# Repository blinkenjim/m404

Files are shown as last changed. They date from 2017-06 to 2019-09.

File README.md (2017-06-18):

M404 Monitor
------------

The M404 monitor is a device to display status for a headless
Raspberry Pi (or any other computer with a USB port).

For more information see doc/design-notes.md.

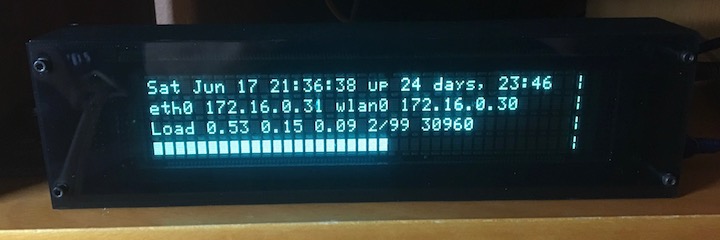
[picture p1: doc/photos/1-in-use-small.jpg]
M404 Monitor in use


The monitor is built around a Futaba M404SD01 Vacuum Fluorescent
Display (VFD) module. This module has a display of 40 characters by 4
lines. In addition to the VFD module, the monitor consists of:

1. A 3D printed case.

2. Laser-cut acrylic front and back covers.

2. An Arduino Nano that drives the VFD module.

3. A Python script that runs on the Raspberry Pi to gather data for
   display.

This project includes all the code, schematics, 3D models, and assembly 
information necessary to build and use an M404 monitor.

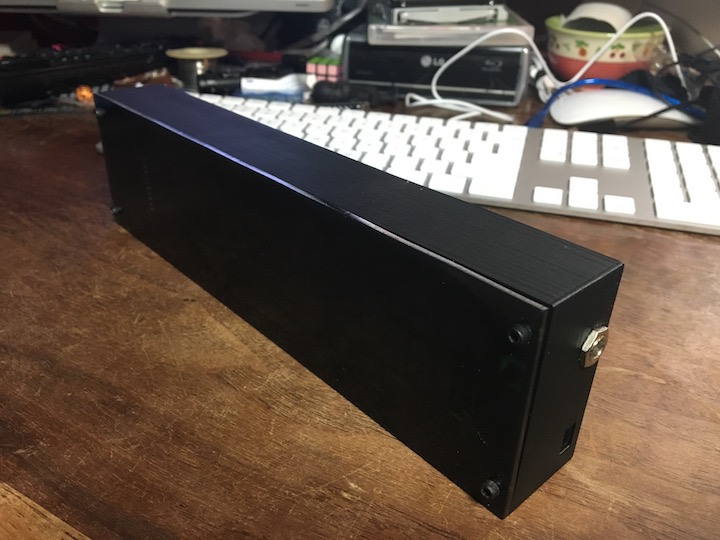
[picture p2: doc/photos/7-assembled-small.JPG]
M404 Monitor Fully Assembled


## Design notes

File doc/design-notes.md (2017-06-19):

M404 Monitor
============

Introduction
------------

The M404 Monitor is a device to display status for a headless
Raspberry Pi (or any other computer with a USB port).

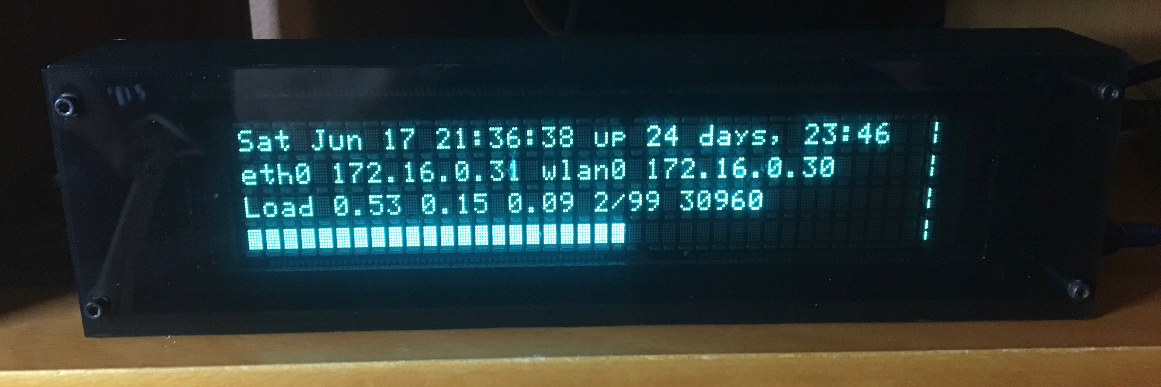
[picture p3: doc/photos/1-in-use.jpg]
M404 Monitor in use


The monitor is built around a Futaba M404SD01 Vacuum Fluorescent
Display (VFD) module. This module has a display of 40 characters by 4
lines. In addition to the VFD module, the monitor consists of:

1. A 3D printed case.

2. Laser-cut acrylic front and back covers.

2. An Arduino Nano that drives the VFD module.

3. A Python script that runs on the Raspberry Pi to gather data for
   display.

3D Printed Case
---------------

The case was designed in Autodesk Fusion. The case is almost 10 inches
long and requires a printer with a fairly large print bed. I printed
mine on a re:3d Gigabot at the Jocelyn H Lee Innovation Lab at the
Freeman branch of the Harris County Public Library in Houston.

I have included an export of the Fusion project files, but should note
that I have never tried to work from an export (Fusion stores its
designs in the cloud, and I always work from these copies).

Also included is an STL model exported from Fusion. **IMPORTANT NOTE**:
when slicing the model for printing, it *MUST* be mirrored along the Y
axis (long axis) or the print will be unusable.

The 3D model files are in the 3d directory.

Laser-Cut Covers
----------------

Included is an SVG file that can be fed to a laser cutter to cut
covers for the case. The SVG file can be used for both the front and
back covers. I use 1/8" translucent grey acrylic for the front cover
and 1/8" opaque black acrylic for the back cover.

The SVG file is in the 3d directory with the STL file.

Arduino Nano
------------

The Nano was chosen for its small size and USB port. The Nano must be
attached to the case with small screws. Most nanos have header pins
soldered to them; these pins make the nano too large to fit in the
case. A nano *without* header pins must be used; these can be found on
Ebay. Wires for power (2) and connection to the VFD module (5) must be
soldered directly to the nano.

The case includes a small port to allow a mini-USB cable to be
attached. Display information is transmitted from the Raspberry Pi
over USB to the nano.

Two Aurdino programs are included:

In arduino/m404-demo is a demo program that displays Lewis Carroll's
poem Jabberwocky on the VFD module. This program can be used to test
the M404 monitor without requiring an external computer to transmit
information over the USB cable.

In arduino/m404-disp is the program that receives information over the
USB connection and drives it to the VFD module.

The reason for using an Arduino as an intermediary to drive the VFD
module, rather than connecting the Raspberry Pi directly to the VFD
module is twofold:

1. The VFD module uses an unusual baud rate and requires monitoring of
   its BUSY signal to keep from losing data.

2. The Arduino program uses a timeout to determine whether the
   Raspberry Pi or its script have stopped running. If a 10-second
   interval passes without any communication from the Raspberry Pi,
   the program will display a message reading "HOST NOT
   RESPONDING". This would not be possible if the Raspberry Pi were
   communicating directly to the VFD module.

The Aurdion uses two serial ports: the built-in serial port on pins 0
and 1 is used to receive information from the Raspberry Pi. A soft
serial port on pins 9 and 10 is used to transmit information to the
VFD module (only the transmit pin, 10, is used and pin 9 is left
unconnected).

Python
------

In the python directory are a pair of scripts that run on the
Raspberry Pi:

1. m404.py is a python script that gathers basic information from the
   Raspberry Pi: date/time, uptime, IP addresses for eth0 and wlan0,
   system load. This information is sent to the nano for display on
   the VFD module. System load is displayed both as text and load
   graph.

2. m404 is a shell script that can be installed in /etc/init.d; this
   allows the python script to be treated as a system service. As a
   system service, linux will automatically start the python script at
   boot, and it can be controlled with the 'service' command:
   e.g. `service m404 start`, `service m404 status`, etc.

Power
-----

A 1/4" hole must be drilled in the case to accept a 2.1mm barrel jack
for power. The hole is not included in the 3D model to allow some
end-user choice of exactly where to locate the jack. I put mine on the
same end of the case as the USB port.

Fasteners
---------

As mentioned above, four tiny screws are required to attach the
Arduino nano to the case. I didn't purchase these screws, but found
four in my small fastener collection (mostly these come from old
devices I've disassembled.

12 larger screws are required: four to attach the VFD module to the
case, and four each to attach the front and backcovers. #4-40 screws
in 1/4" or 3/8" length will work nicely. I prefer [socket cap, alloy
steel black oxide finish] [1] bolts from Bolt Depot.

Assembly Notes
--------------

The CN1 connector on the VFD module is a 2x13 pin IDC header. The
simplest way to connect is to use a matching crimp-on plug with a
26-pin ribbon cable. Only a few of the wires are required, and the
others can be cut short - but leave an inch or two of the full ribbon
cable to give yourself something to grasp when disconnecting the
plug.

When I assemble my M404 monitor, I only had a 2x10 pin plug handy, so
I used that instead. It required that I clip pins 21 and 22 off the
IDC header, otherwise they interfere with the IDC plug. To connect to
Vcc (pins 23 and 24) and GND (pins 25 and 26), I soldered wires
directly to the pins in the header.

It would also be possible to forego the IDC plug entirely, and just
solder directly to the pins in the header.

Reference Information
---------------------

A copy of the documentation for the Futaba M404SD01 Vacuum Fluorescent
Display module is in the ref directory.

Schematic
---------

An Eagle project and schematic are included in the eagle directory
showing the connections required between the Arduino nano, VFD module,
and power jack.

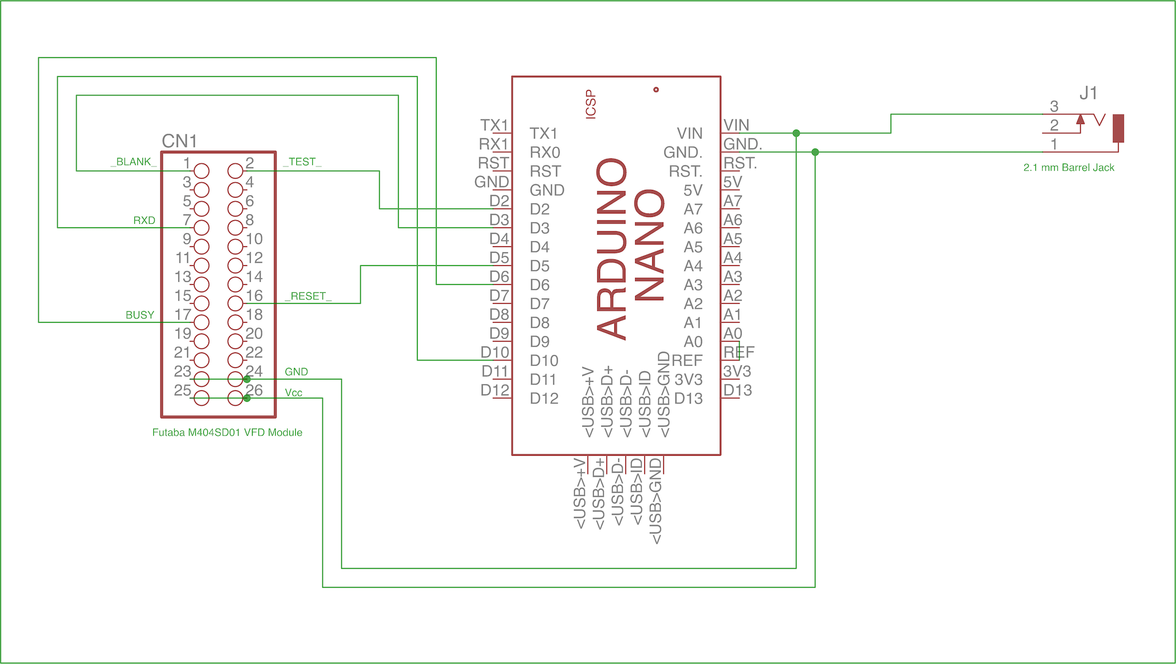
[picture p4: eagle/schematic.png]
Schematic


Photos
------

The M404 monitor with the front cover removed:

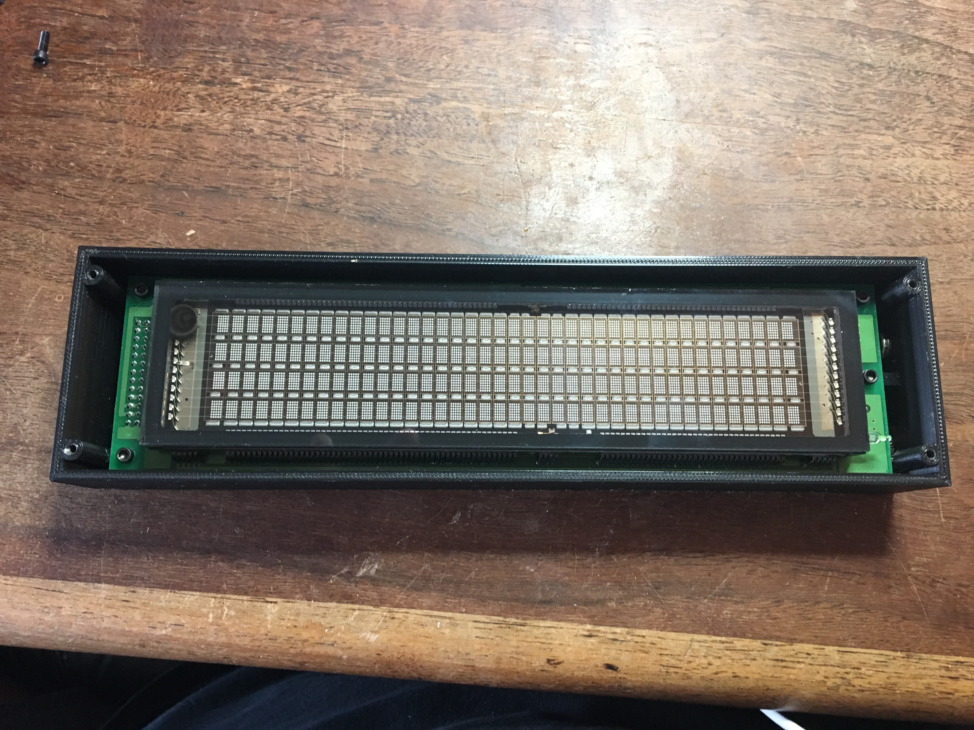
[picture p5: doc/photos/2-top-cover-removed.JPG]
Front View


The M404 monitor with the back cover removed:

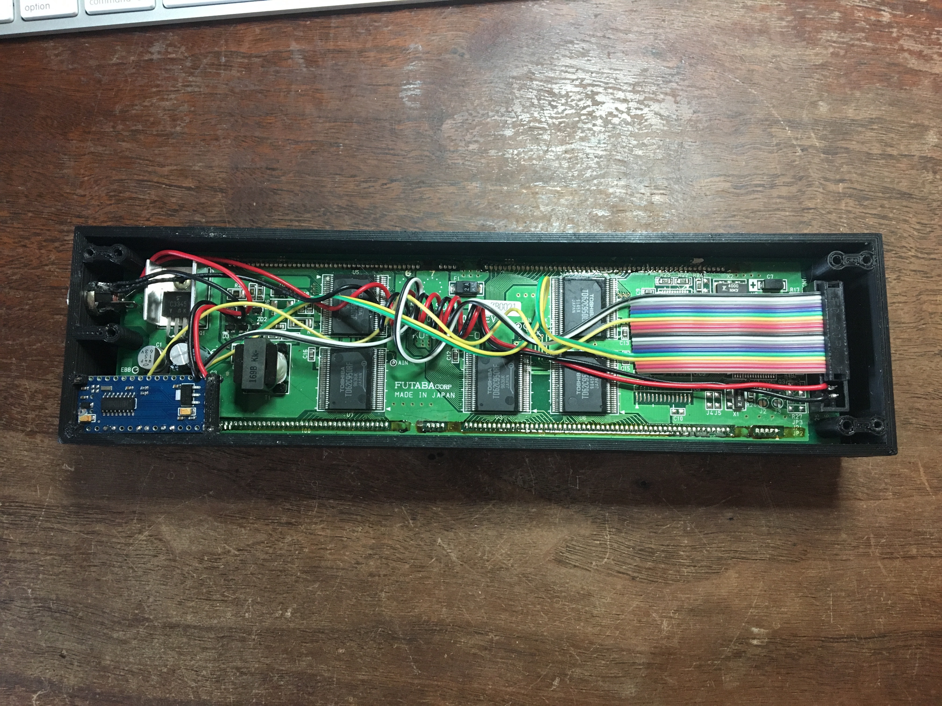
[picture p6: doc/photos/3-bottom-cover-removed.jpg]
Back view


Detail view of the Arduino nano from the bottom:

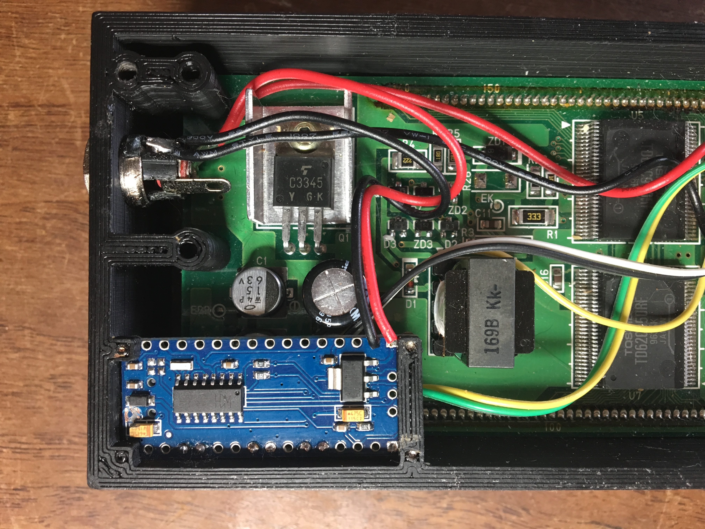
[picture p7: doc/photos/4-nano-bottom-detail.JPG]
Nano detail view back


Detail view of the Arduino nano from the front (with the VFD module removed):

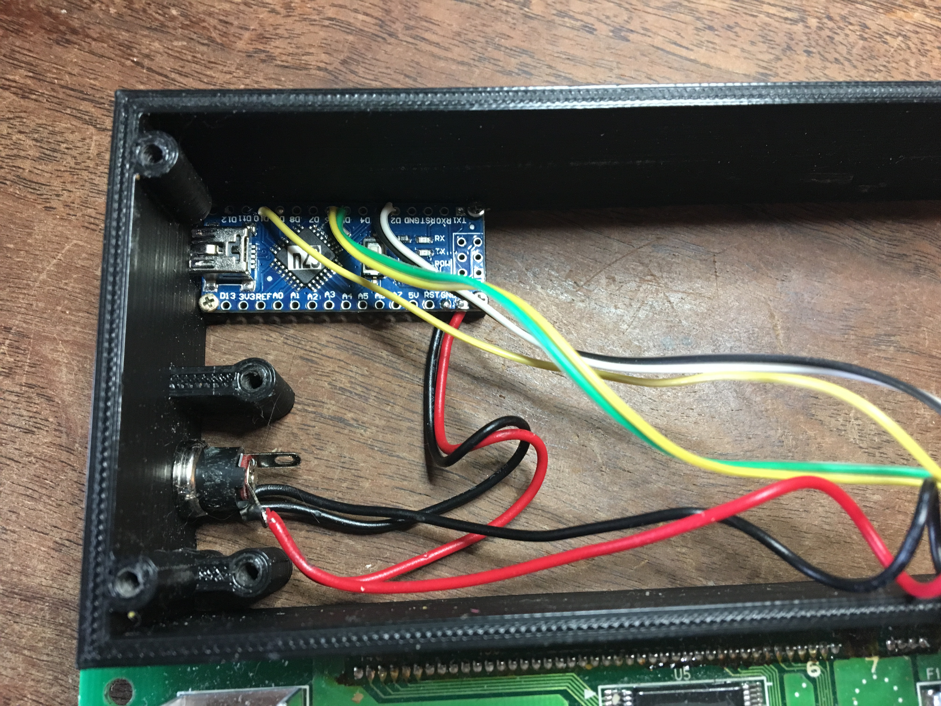
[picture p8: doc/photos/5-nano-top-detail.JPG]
Nano detail view front


Detail view of the interface connector on the VFD module:

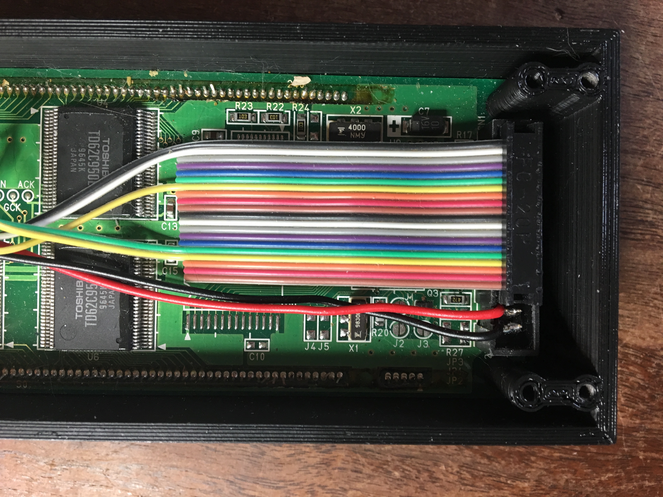
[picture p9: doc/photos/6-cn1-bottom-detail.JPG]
CN1 detail view front


The M404 Monitor fully assembled:

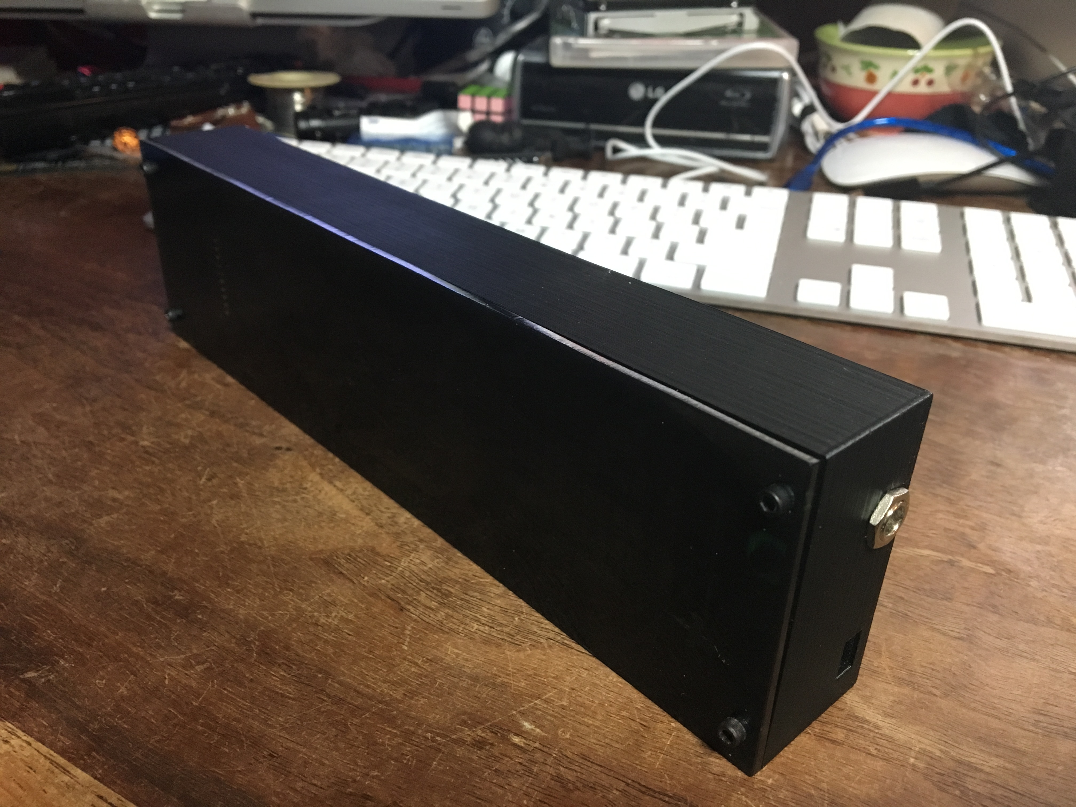
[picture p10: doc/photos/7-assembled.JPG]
Fully assembled


[1]: https://www.boltdepot.com/Socket_cap_Alloy_steel_black_oxide_finish_4-40.aspx?Selected=7872

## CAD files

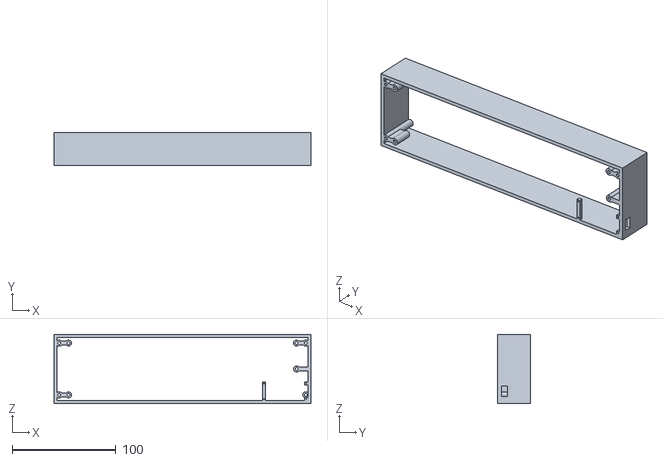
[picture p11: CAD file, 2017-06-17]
3d/Project M404 v11.stl
248.0 x 32.0 x 67.0

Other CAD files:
3d/fusion/Project M404 v11.f3d

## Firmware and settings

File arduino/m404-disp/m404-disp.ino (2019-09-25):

// M404 - A vacuum fluorescent display monitor for Raspberry Pi.
//
// Copyright (c) 2017 James Thompson
//
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
#include <SoftwareSerial.h>

const unsigned int pin_blank_ = 3;
const unsigned int pin_test_ = 2;
const unsigned int pin_reset_ = 5;
const unsigned int pin_busy = 6;

const unsigned int pin_nc = 9;
const unsigned int pin_rxd = 10;

SoftwareSerial mySerial(pin_nc, pin_rxd);

// We must delay a short time after writing each character, or else
// or the module receives garbled text. 440 microseconds seems to be
// the minimum amount we can delay. Also, we must check the busy
// pin before writing the next character. This prevents garbling when
// the text wraps from the end of the display to the beginning.

#define INTERCHAR_DELAY_ONLY 0

// Define the baud and delay values. (Yes, this is a fairly weird
// rate, but it is what the VFD module seems to like.)

#define BAUD 62500
#define DELAY 440

#if defined(INTERCHAR_DELAY_ONLY) && (INTERCHAR_DELAY_ONLY > 0)
#define INTERCHAR_DELAY delayMicroseconds(DELAY)
#else
#define WAIT for (int busy = HIGH; busy == HIGH; busy = digitalRead(pin_busy)) {} 
#define INTERCHAR_DELAY { WAIT; delayMicroseconds(DELAY); WAIT; }
#endif

// Function to print a string to the VFD module with intercharacter delay.

void metered_print(const char *s)
{
    while (*s)
    {
	mySerial.write(*s++);
	INTERCHAR_DELAY;
    }
}

// Function to print a string of specific length to the VFD module
// with intercharacter delay.

void metered_write(const unsigned char *s, unsigned int len)
{
    for(int i = 0; i < len; i++)
    {
	mySerial.write(*s++);
	INTERCHAR_DELAY;
    }
}

// Function to write a single character to the VFD module with
// postcharacter delay.

void metered_write(const unsigned char c)
{
    mySerial.write(c);
    INTERCHAR_DELAY;
}

// The main Arduino setup routine

void setup()
{
    // Set the appropriate modes for the various I/O pins.
    pinMode(pin_busy, INPUT);
    pinMode(pin_blank_, OUTPUT);
    pinMode(pin_test_, OUTPUT);  
    pinMode(pin_reset_, OUTPUT);

    // Reset the VFD module.
    digitalWrite(pin_blank_, HIGH);
    digitalWrite(pin_test_, HIGH);
    digitalWrite(pin_reset_, HIGH);

    // Pause for effect.
    delay(1);

    // Setup the serial port for writing to the VFD.
    mySerial.begin(BAUD);

    // Setup the serial port for writing to the Arduino IDE monitor.
    Serial.begin(115200, SERIAL_8N1);

    // Pause for effect.
    delay(1000);

    // Set the display brightness.
    unsigned char dim_cmd[] = { 0x04, 0xff };
    metered_write(dim_cmd, 2);
}

// The main Arduino event loop

void loop()
{
    metered_print("M404 monitor starting...\n\n");

    // Variables for determining whether we've had a timeout.
    unsigned long last_millis = millis();
    unsigned long now_millis = last_millis;

    // We loop forever, reading characters from the host, and writing
    // those characters to the VFD module.
    while(true)
    {
	// While characters are coming in...
	while (Serial.available() > 0)
	{
	    // Read the character from the host.
	    unsigned char c = Serial.read();

	    // Write the character to the VFD.
	    metered_write(c);
	    last_millis = millis();
	}
    
	now_millis = millis();
    
	if (now_millis < last_millis)
	{
	    // Handle wraparound
	    last_millis = now_millis;
	}
    
	if ((now_millis - last_millis) > 10000) // More than ten seconds since we heard from host?
	{
	    metered_write(0x0b);
	    metered_write(0x13);
	    metered_print("\r\r      *** HOST NOT RESPONDING ***");

	    // Wait for some serial data to appear.
	    while (Serial.available() == 0)
	    {
	    }
	}
    }
}

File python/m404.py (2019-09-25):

#!/usr/bin/python

# M404 - A vacuum fluorescent display monitor for Raspberry Pi.
#
# Copyright (c) 2017 James Thompson
#
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
# Import the various python packages we need.

import socket
import time
import subprocess
from netifaces import interfaces, ifaddresses, AF_INET
import serial
import re
import math

from datetime import timedelta
import signal, os

# Define a signal handler.

def handler(signum, frame):
    ser404.write("\x0b")
    ser404.write("Stopping on signal " + str(signum))
    os.abort()

looptime = 60
ips=''

ser404 = serial.Serial('/dev/ttyUSB0', 115200)

# Catch any of the signals that might cause the process to exit. Note
# that by catching exceptions (later on) seems to cause these signlas
# to get caught as exceptions, so the signal handler does not actually
# run.
#signal.signal(signal.SIGABRT, handler)
signal.signal(signal.SIGALRM, handler)
signal.signal(signal.SIGBUS, handler)
signal.signal(signal.SIGFPE, handler)
signal.signal(signal.SIGHUP, handler)
signal.signal(signal.SIGILL, handler)
signal.signal(signal.SIGINT, handler)
signal.signal(signal.SIGPIPE, handler)
signal.signal(signal.SIGPOLL, handler)
signal.signal(signal.SIGQUIT, handler)
signal.signal(signal.SIGSEGV, handler)
#signal.signal(signal.SIGSTOP, handler) # Can't catch?
signal.signal(signal.SIGSYS, handler)
signal.signal(signal.SIGTERM, handler)
#signal.signal(signal.SIGTSTP, handler) # Don't want to catch
#signal.signal(signal.SIGTTIN, handler) # Don't want to catch
#signal.signal(signal.SIGTTOU, handler) # Don't want to catch
signal.signal(signal.SIGTRAP, handler)
signal.signal(signal.SIGURG, handler)
signal.signal(signal.SIGUSR1, handler)
signal.signal(signal.SIGUSR2, handler)

ser404.write("\x0b")                    # Clear the display
ser404.write("\x13")                    # Set overwrite mode
ser404.write("\x04\xFF")                # Set brightness to max

ser404.write("\x03\xfc\xfc\x63\x18\xc7\xe0")
ser404.write("\x03\xfd\xaa\xaa\xaa\xaa\xaa")

def padout(s):
    s = s + '                                        ' #
    s = s[0:39]
    s += '|'
    return s

#try:
if True:
    while 1:
        allifaces = []
        for ifaceName in interfaces():
            if ifaceName[0:2] != "lo":
                addresses = [i['addr'] for i in ifaddresses(ifaceName).setdefault(AF_INET, [{'addr':'-'}] )]
                name = ifaceName + ' ' + ', '.join(addresses)
                allifaces.append(name)

        ips = ' '.join(allifaces)

        rawup = "0 0"
        with open('/proc/uptime', 'r') as f:
            rawup = f.readline()
            f.close()

        rawsplit = rawup.split()[0]
        uptime_seconds = float(rawsplit)
        # uptime_seconds += 99 * (24 * 60 * 60)
        # uptime_seconds += 23 * 60 * 60

        with open('/proc/loadavg', 'r') as f:
            rawload = f.readline()
            f.close

        load1m = rawload.split()[0]
        load1m = 0.0 + float(load1m)

        (fload, iload) = math.modf(load1m)

        loadbricks = 40 * fload
        ceilbricks = int(math.ceil(loadbricks))

        if ceilbricks > 40:
            ceilbricks = 40

        if ceilbricks == 0:
            g_msg = padout("\xfd")
        else:
            g_msg = padout(ceilbricks * "\x7f")

        cpucount = iload
        cpucounti = int(cpucount)
        
        if cpucounti > 40:
            cpucounti = 40

        for i in range(cpucounti):
            g_msg = g_msg[:i] + '\xfc' + g_msg[i:]
            
        tdelt = timedelta(seconds = uptime_seconds)

        if (uptime_seconds > (10 * 24 * 60 * 60)):
            us = str(tdelt).split(':', 2)
            uptime_string = 'up ' + us[0] + ':' + us[1]
        else:
            uptime_string = 'up ' + str(tdelt).split('.', 2)[0]
            
        # If uptime is less than a day, display the time zone and year
        if (uptime_seconds < (24 * 60 * 60)):
            date = subprocess.check_output(['date', '+%a %b %d %H:%M:%S %Z %Y']).strip()
        else:
            date = subprocess.check_output(['date', '+%a %b %d %H:%M:%S']).strip()

            
        # if uptime_seconds < (24 * 60 * 60):
        #     uptime_string = str(tdelt).split('.', 2)[0]
        # else:
        #     us = str(tdelt).split(':', 2)
        #     uptime_string = us[0] + ':' + us[1]
        #     uptime_string = re.sub('\s*day[s]?,\s*', 'd ', uptime_string)
        
        # date = subprocess.check_output(['date', '+%a %b %d %H:%M:%S %Z %Y']).strip()

#    print uptime_string
#    print date

#    ser404.write("\x04\x20")           # Set brightness to minimum (good for photos)

        load = ' '.join(rawload.split())
        load = 'Load ' + load
        # print "'" + load + "'"

        u_msg = padout(date + ' ' + uptime_string)
        i_msg = padout(ips)
        l_msg = padout(load)
        g_msg = padout(g_msg)

        # print "u_msg length =", len(u_msg), '|', u_msg, '|'
        # print "i_msg length =", len(i_msg), '|', i_msg, '|'
        # print "l_msg length =", len(l_msg), '|', l_msg, '|'

        ser404.write("\x10\x00")            # Home the display without clearing
        ser404.write("\x13")                # Ensure we're in overwrite mode

        ser404.write(u_msg)
        time.sleep(0.1)
        ser404.write(i_msg)
        time.sleep(0.1)
        ser404.write(l_msg)
        time.sleep(0.1)
        ser404.write(g_msg)
#        ser404.write(("\x7f" * 20) + ("\xfd" * 20))

        time.sleep(0.2)
    #    break

#except:
#    ser404.write("\x0b")
#    ser404.write("M404 monitor stopping...")

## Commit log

2017-06-17 Add new directory to hold STL and associated files.
2017-06-17 Add Fusion project.
    [Project M404 v11.f3d]
2017-06-17 Add Facia and STL files.
    [Project M404 v11.stl]
2017-06-18 Move Arduino sources to subdirectories as required by the Arduino IDE's silly rules.
2017-06-18 Add Eagle project and schematic.
    [m404.sch]
2017-06-18 Revert "Fix breakage."
    This reverts commit 6aac1756002e191bb180a9600b239124c896345d
    [m404-disp.ino]

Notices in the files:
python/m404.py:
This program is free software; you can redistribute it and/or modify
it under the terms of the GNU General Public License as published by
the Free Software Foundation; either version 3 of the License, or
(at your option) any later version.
